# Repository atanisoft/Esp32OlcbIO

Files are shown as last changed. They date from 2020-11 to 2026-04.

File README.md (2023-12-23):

# ESP32 OpenLCB IO Board

The ESP32 OpenLCB IO Board is a basic OpenLCB (LCC) node offering 14 input/output
capable pins, and two that are input only. Additionally all IO pins are exposed
through two 13 pin headers which allows for extending the functionality of 
the base board using a daughter board approach.

## Powering the ESP32 OpenLCB IO Board

The ESP32 OpenLCB IO Board can be powered from an external power supply (12V) on
J5 connector, or using the OpenLCB (LCC) Bus power on RJ45. To enable powering
from the external supply, bridge pins 1 and 2 on JP1. To power from the OpenLCB
(LCC) Bus, bridge pins 2 and 3. Note that when using the USB connector on the
ESP32 module JP1 should not have any pins bridged.

### OpenLCB (LCC) Power requirements

The ESP32 OpenLCB IO Board will draw around 100mA from the OpenLCB (LCC) Bus when
the PWR_POS pin provides 15VDC. If the PWR_POS pin provides less, the node may
draw more current from the bus.

### External Power requirements

The external power supply should be rated for at least 12VDC 500mA to ensure
sufficient current is available for the node to operate as intended.

### Node Brownout detection

If the ESP32 detects a brownout condition it will attempt to produce the
well-known event `01.00.00.00.00.00.FF.F1` soon after startup. This delivery
is not guaranteed.

## Pin Mapping

By default almost all pins are exposed for general IO usage by the node,
however a few pins have specialized usage as part of the screw terminals or
expansion headers.

| GPIO Pin | Usage | Notes |
| --- | ----- | ----- |
| 0 | IO4 | has pull-up resistor |
| 1 | UART0 TX | not exposed |
| 2 | IO5 | has pull-down resistor |
| 3 | UART0 RX | not exposed |
| 4 | CAN RX | has pull-down resistor |
| 5 | CAN TX | has pull-up resistor |
| 6-11 | NOT AVAILABLE | connected to on chip flash |
| 12 | IO7 | has pull-down resistor |
| 13 | IO8 | |
| 14 | IO16 | |
| 15 | IO6 | has pull-up resistor |
| 16 | IO3 | |
| 17 | IO2 | |
| 18 | IO1 | |
| 19 | I2C - SDA | |
| 20 | NOT AVAILABLE | NOT AVAILABLE |
| 21 | I2C - SCL | |
| 22 | Node Activity LED | active low |
| 23 | WiFi Active LED | active low |
| 24 | NOT AVAILABLE | NOT AVAILABLE |
| 25 | IO13 | |
| 26 | IO14 | |
| 27 | IO15 | |
| 28-31 | NOT AVAILABLE | NOT AVAILABLE |
| 32 | IO11 | |
| 33 | IO12 | |
| 34 | IO9 | INPUT ONLY, has pull-up resistor |
| 35 | IO10 | INPUT ONLY |
| 36 (SVP) | User button | INPUT ONLY, has pull-up resistor |
| 37 | NOT AVAILABLE | NOT AVAILABLE |
| 38 | NOT AVAILABLE | NOT AVAILABLE |
| 39 (SVP) | Factory Reset button | INPUT ONLY, has pull-up resistor |

### Input only pins

The four pins marked as INPUT ONLY in the table above have a 10k pull-up to
3v3 and a 100nF capacitor for debounce.

### IO4, IO5, IO6, IO7 Usage Note

IO4 and IO6 typically have a pull-up resistor. IO5 and IO7 typically have a
pull-down resistor that can not be disabled. Keep this in mind as this may
require adjustments to usage patterns.

## Base ESP32 OpenLCB IO PCB

The ESP32 OpenLCB IO Board PCB can be found under the pcb directory and is
provided as both KiCad files and generated Gerber files.

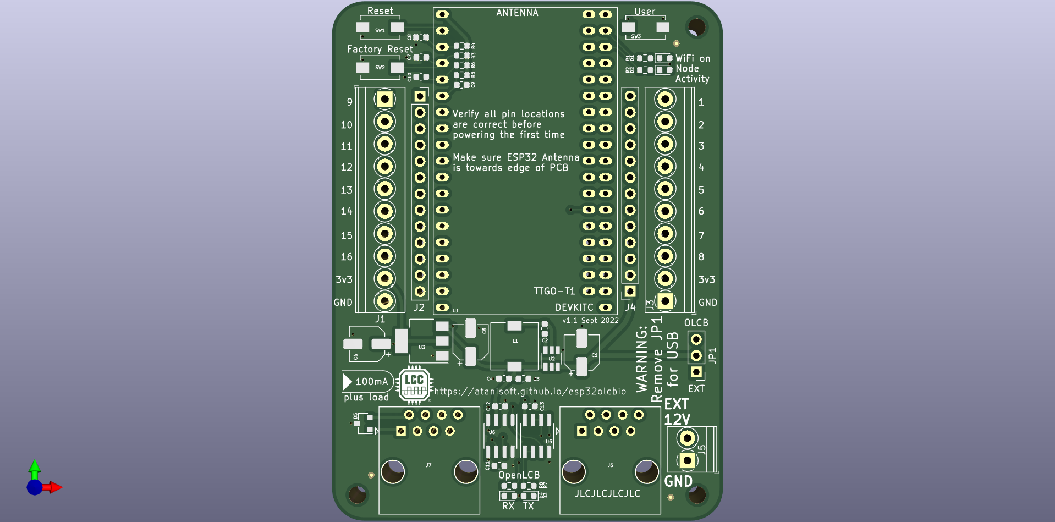
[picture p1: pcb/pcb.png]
PCB Render


**NOTE:** U6 (CAN Transceiver) BOM line item references IFX1050GVIOXUMA1 which is no longer in production, please use one of the following instead:

* TJA1057GT/3J
* TCAN1051
* MCP2562

### PCBWay project

The ESP32 OpenLCB IO PCB has been shared via PCBWay [here](https://www.pcbway.com/project/shareproject/ESP32_OpenLCB__LCC__IO_PCB.html).

### Mouser BOM

The ESP32 OpenLCB IO Board components have been entered on Mouser for easy ordering
via the following shared carts:
- [single PCB](https://www.mouser.com/ProjectManager/ProjectDetail.aspx?AccessID=6d57d6cf6a)
- [five PCBs](https://www.mouser.com/ProjectManager/ProjectDetail.aspx?AccessID=a15be25217)

Ordering in larger quantities can decrease the per-PCB cost considerably. In
the case of resistors and capacitors it is recommended to order 100 of each
as they are tiny and easily lost. Other parts can often be substituted as long
as they have the same footprint and pinout. The pin headers will need to be cut
to length in both of the carts above, in the case of the five PCBs option there
should be enough to populate all five PCBs for the ESP32 *AND* the extension
board (when available).

#### Optional parts

The following parts are optional depending on board usage:

| Part | Mouser # | Notes |
| ---- | --- | ----- |
| J2, J4 | 571-6-534237-1 | These are only needed for attaching an extension daughter board. |
| J5 | 523-NY0210800000G | This is only required if using an external power supply. |

#### Alternative part numbers

The following parts have compatible alternatives:

| Part | Default Mouser # | Alternative Mouser # | Notes |
| ---- | --- | --- | ----- |
| J2, J4 | 571-6-534237-1 | 992-13FX1-254MM, 485-598, 485-4158, 485-4156, 485-4159, 485-4157, 485-4155, 485-4160 | Parts 485-XXXX will need to be cut to the correct length. |
| J6, J7 | 571-5569284-1 | 534-949 or 493-HCJV1-812UK |

## Extending the base board

The ESP32 OpenLCB IO Board can be extended by using the pcb-ext daughter board
files as a basis for creating a compatible extension PCB. This PCB sits on top
of the base board.

### 16 Channel PWM generator expansion

The first expansion board is the 16 Channel PWM generator board, this is usable
for Servo or LED control. This expansion board utilizes a PCA9685 to generate
16 PWM signals which are routed to a three pin header (GND, 5V and PWM) for
each output.

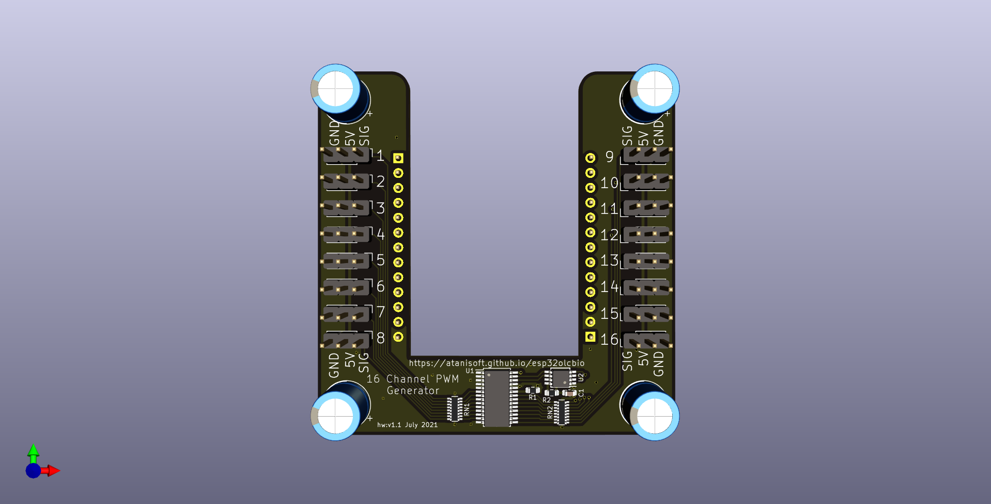
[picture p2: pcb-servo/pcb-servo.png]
Extension PCB as Servo controller


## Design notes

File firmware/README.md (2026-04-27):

# ESP32 OpenLCB IO Board Firmware

## Features

The ESP32 OpenLCB IO Board supports all features of the base IO Board PCB. Some
of the functionality has been customized in this firmware as described below.

### Input/Output pins

The ESP32 OpenLCB IO Board firmware exposes sixteen input/output connections with
two of these being input only. Additionally there are two buttons which can be
used to generate events from the base IO board.

### Factory reset

The Factory Reset button on the base IO Board can be held during startup of the
node to initiate one of the behavors below:

* Hold for five seconds to regenerate event identifiers for all eighteen
input/output pins.
* Hold for ten seconds to erase all OpenLCB (LCC) configuration data and return
the node to it's default configuration. NOTE: This will not clear persistent
WiFi settings.
* Hold both the Factory Reset and User buttons during startup to force the node
into the bootloader download mode. This mode can be used to update the firmware
from within JMRI.
* Press anytime after boot to generate a pair of events.

### User Button

Pressing the User button will generate a pair of events.

## Building

The ESP32 OpenLCB IO Board depends on at least ESP-IDF v5.2.x and will not build with
earlier versions. Note that it will not build successfully avove ESP-IDF v5.4.4 due to
ESP-IDF changes in TWAI and other peripherals.

### Configuring ESP-IDF build environment

For Windows environments please use the [Windows Installer](https://docs.espressif.com/projects/esp-idf/en/latest/esp32/get-started/windows-setup.html)
and select `release/v5.1` when prompted for a version. It is only necessary to
install the basic command line tools, Eclipse (or other IDEs) are optional.

For Linux / Mac environments it is recommended to use `git clone` to setup and
maintain the ESP-IDF build enviornment:
```
git clone https://github.com/espressif/esp-idf.git --depth 1 --branch release/v5.1 esp-idf-v5.1 --recursive
cd esp-idf-v5.1
sh install.sh
```

To use the ESP-IDF build enviornment start a commandline shell and source / run the
`export.sh`, `export.bat` or `export.ps1` script based on your shell.

### Configuring and Building Esp32OlcbIO

Enter the ESP-IDF build environment and navigate to the Esp32OlcbIO source
directory. If this is the first time building the source code it is a good idea
to run `idf.py menuconfig` and configure the default configuration settings for
the Esp32OlcbIO firmware. In general it is not necessary to modify any
configuration settings outside of `OpenLCB Configuration` and `WiFi Configuration`.

Once the configuration has been completed run `idf.py build` to compile the
firmware. If there are no errors you can proceed to programming the firmware.

### Programming the firmware

There are a couple ways to flash the firwmare to the ESP32:

* `idf.py flash` - This leverages the ESP-IDF build environment and should
automatically detect the appropriate communications port for the ESP32.
* [Browser based flash utility](https://espressif.github.io/esptool-js/)

The [Browser based flash utility](https://espressif.github.io/esptool-js/)
only supports using Chrome based browsers, attempting to use Safari will
result in an error dialog being displayed. If you are using this approach,
plug in the ESP32 to an available USB port and click the `Connect` button
which will prompt for the communication port (COM?? on Windows, /dev/ttyACM?
on Linux). Once connected the console output should display information about
the connected ESP32 module.

Enter the following `Flash Address` and `File` using the `Add File` button
as needed:

* 0x1000 - build/bootloader/bootloader.bin
* 0x8000 - build/partition_table/partition-table.bin
* 0xe000 - build/ota_data_initial.bin
* 0x10000 - build/ESP32OlcbIO.bin

Click on `Program` and the binaries will be sent to the ESP32 and it should
reboot automatically.

### Monitoring the firmware startup

After programming a new firmware it is generally a good idea to monitor the
startup of the Esp32OlcbIO firmware to confirm that there are no issues
preventing successful startup.

The easiest way to do this is with `idf.py monitor`.

NOTE: If the ESP32 is *NOT* plugged into the IO PCB it will be necessary to
add a jumper wire between the 3v3 pin and GPIO 39 (may be labeled as SVN or
VN) to prevent Factory Reset from being initiated on startup.

## Updating the firmware

The easiest way to update the firmware on the ESP32 OpenLCB IO Board is to upload
it via the JMRI Firmware Upload tool via the TWAI (CAN) interface since you do not
need to remove the ESP32 OpenLCB IO Board from the train layout. Alternatively,
the updated firmware can be uploaded via the web interface.

If the ESP32 is not connected to the PCB it will be necessary to add a jumper
wire between 3v3 and both the Factory Reset button pin (default 39/SVN) and the
User button pin (default 36/SVP) to prevent the ESP32 from entering bootloader
mode.

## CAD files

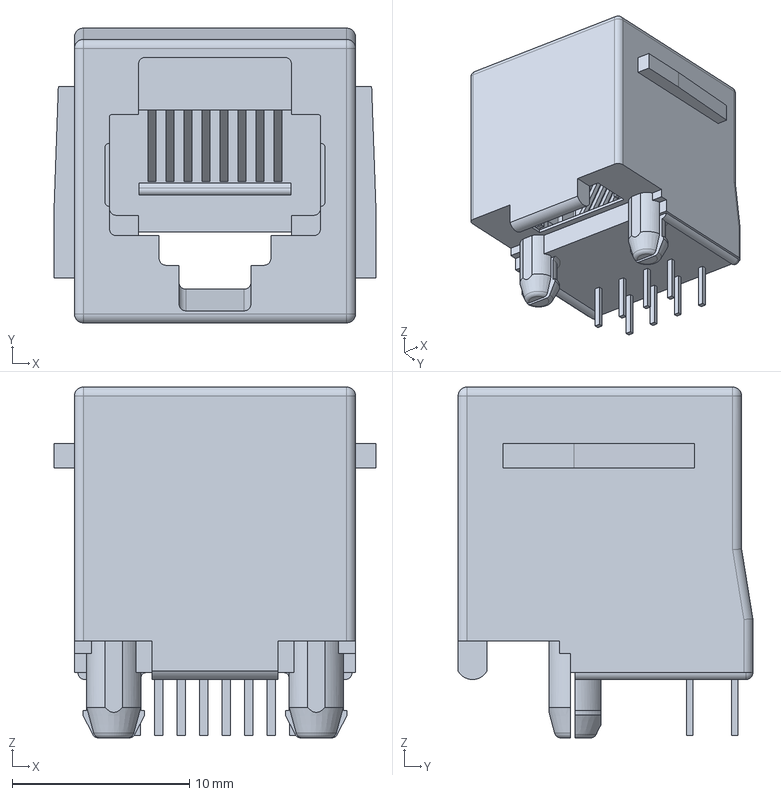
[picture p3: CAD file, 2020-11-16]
pcb/Components/c-5520259-4-c-3d.stp
18.2 x 16.6 x 19.8 mm

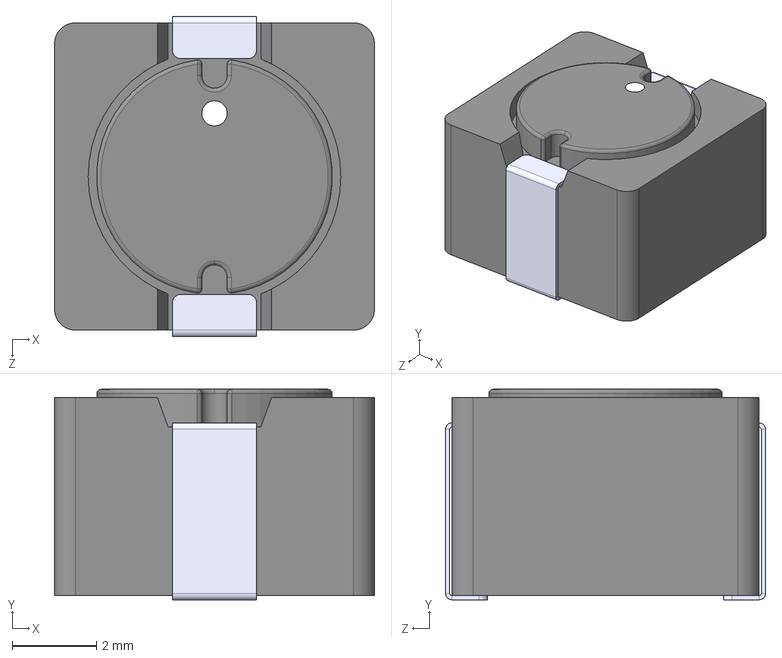
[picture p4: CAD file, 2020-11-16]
pcb/Components/B1047AS-221M=P3--3DModel-STEP-46669.STEP
7.60 x 5.00 x 7.60 mm

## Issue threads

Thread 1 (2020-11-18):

Web: Rework CDIRequestProcessor to queue requests

atanisoft, 2020-11-18:
Currently the code will create N instances of `CDIRequestProcessor` where N is the number of requests. This causes the heap to become dangerously low at times and can lead to heap fragmentation.

It would be better to allocate a single instance of `CDIRequestProcessor` and send it requests similar to `openlcb::MemoryConfigClient`.

Closed 2022-11-25.

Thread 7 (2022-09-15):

Error during compiling esp32io_bootloader.cpp

dwightkelly, 2022-09-15:
a clean clone of the master branch has the compiler error:
```
In file included from ../main/esp32io_bootloader.cpp:39:
../components/OpenMRNIDF/src/freertos_drivers/esp32/Esp32BootloaderHal.hxx: In function 'void esp32_bootloader_run(uint64_t, gpio_num_t, gpio_num_t, bool)':
../components/OpenMRNIDF/src/freertos_drivers/esp32/Esp32BootloaderHal.hxx:354:12: error: enumeration value 'CHIP_ESP32H2' not handled in switch [-Werror=switch]
     switch (chip_info.model)
            ^
```

This enum value was added on 1/7/22 in [0f6073123ebb836d6515858a56661fb36ddd23e5](https://github.com/atanisoft/OpenMRNIDF/commit/0f6073123ebb836d6515858a56661fb36ddd23e5)

The servo branch is using newer version (9/18/22)  [10b7e3cf3c65cf0e71788427e6c3227b100f4802](https://github.com/atanisoft/OpenMRNIDF/commit/10b7e3cf3c65cf0e71788427e6c3227b100f4802)

atanisoft, 2022-09-15:
Master should be pointing to [217a5db2465b9091a106ce9ca476a6f37ec6f4dd](https://github.com/atanisoft/OpenMRNIDF/tree/217a5db2465b9091a106ce9ca476a6f37ec6f4dd) which has no reference to `CHIP_ESP32H2` that I can find.
.
This will be resolved on the `servo` branch which syncs to the latest OpenMRNIDF and switches to ESP-IDF v4.4 (master uses v4.3)

dwightkelly, 2022-09-15:
I must have somehow forced OpenMRNIDF to HEAD.

Closed 2022-11-25.

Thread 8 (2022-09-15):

Add note about firmware update of ESP32 board when removed from IO board

dwightkelly, 2022-09-15:
Add a note about needing to connect SVP (pin 36) and SVN (pin 39) to 3.3v if updating firmware on ESP32 board when it's removed from IO board

Closed 2022-11-25.

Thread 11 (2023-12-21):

Cannot build with esp-idf 4.4

utement, 2023-12-21:
I cant build firmware with esp-idf 4.4. Looks like dependencies don't match.

`
bash-5.2$ idf.py menuconfig
Executing action: menuconfig
Running ninja in directory /Users/utement/Projects/esp/Esp32OlcbIO/firmware/build
Executing "ninja menuconfig"...
[0/1] cd /Users/utement/Projects/esp/Esp32OlcbIO/firmware/build && /Users/utement/.espressif/python_env/idf5....F_TARGET=esp32 --env IDF_ENV_FPGA= --output config /Users/utement/Projects/esp/Esp32OlcbIO/firmware/sdkconfig
Loading defaults file /Users/utement/Projects/esp/Esp32OlcbIO/firmware/sdkconfig.defaults...
/Users/utement/Projects/esp/Esp32OlcbIO/firmware/sdkconfig.defaults:102 CONFIG_ESP_TASK_WDT was replaced with CONFIG_ESP_TASK_WDT_INIT
TERM environment variable is set to "xterm-256color"
/Users/utement/.espressif/python_env/idf5.0_py3.10_env/lib/python3.10/site-packages/menuconfig.py: /Users/utement/Projects/esp/esp-idf-5.0/components/esp_psram/./esp32/Kconfig.spiram:62: '/Users/utement/Projects/esp/esp-idf-4.4/components/esp_psram/Kconfig.spiram.common' not found (in 'source "$IDF_PATH/components/esp_psram/Kconfig.spiram.common"    # insert non-chip-specific items here'). Check that environment variables are set correctly (e.g. $srctree, which is unset or blank). Also note that unset environment variables expand to the empty string.
FAILED: CMakeFiles/menuconfig /Users/utement/Projects/esp/Esp32OlcbIO/firmware/build/CMakeFiles/menuconfig
cd /Users/utement/Projects/esp/Esp32OlcbIO/firmware/build && /Users/utement/.espressif/python_env/idf5.0_py3.10_env/bin/python /Users/utement/Projects/esp/esp-idf-5.0/tools/kconfig_new/prepare_kconfig_files.py --list-separator=semicolon --env-file /Users/utement/Projects/esp/Esp32OlcbIO/firmware/build/config.env && /Users/utement/.espressif/python_env/idf5.0_py3.10_env/bin/python /Users/utement/Projects/esp/esp-idf-5.0/tools/kconfig_new/confgen.py --list-separator=semicolon --kconfig /Users/utement/Projects/esp/esp-idf-5.0/Kconfig --sdkconfig-rename /Users/utement/Projects/esp/esp-idf-5.0/sdkconfig.rename --config /Users/utement/Projects/esp/Esp32OlcbIO/firmware/sdkconfig --defaults /Users/utement/Projects/esp/Esp32OlcbIO/firmware/sdkconfig.defaults --env-file /Users/utement/Projects/esp/Esp32OlcbIO/firmware/build/config.env --env IDF_TARGET=esp32 --env IDF_ENV_FPGA= --dont-write-deprecated --output config /Users/utement/Projects/esp/Esp32OlcbIO/firmware/sdkconfig && /Users/utement/.espressif/python_env/idf5.0_py3.10_env/bin/python /Users/utement/Projects/esp/esp-idf-5.0/tools/check_term.py && /opt/local/bin/cmake -E env COMPONENT_KCONFIGS_SOURCE_FILE=/Users/utement/Projects/esp/Esp32OlcbIO/firmware/build/kconfigs.in COMPONENT_KCONFIGS_PROJBUILD_SOURCE_FILE=/Users/utement/Projects/esp/Esp32OlcbIO/firmware/build/kconfigs_projbuild.in KCONFIG_CONFIG=/Users/utement/Projects/esp/Esp32OlcbIO/firmware/sdkconfig IDF_TARGET=esp32 IDF_ENV_FPGA= /Users/utement/.espressif/python_env/idf5.0_py3.10_env/bin/python -m menuconfig /Users/utement/Projects/esp/esp-idf-5.0/Kconfig && /Users/utement/.espressif/python_env/idf5.0_py3.10_env/bin/python /Users/utement/Projects/esp/esp-idf-5.0/tools/kconfig_new/confgen.py --list-separator=semicolon --kconfig /Users/utement/Projects/esp/esp-idf-5.0/Kconfig --sdkconfig-rename /Users/utement/Projects/esp/esp-idf-5.0/sdkconfig.rename --config /Users/utement/Projects/esp/Esp32OlcbIO/firmware/sdkconfig --defaults /Users/utement/Projects/esp/Esp32OlcbIO/firmware/sdkconfig.defaults --env-file /Users/utement/Projects/esp/Esp32OlcbIO/firmware/build/config.env --env IDF_TARGET=esp32 --env IDF_ENV_FPGA= --output config /Users/utement/Projects/esp/Esp32OlcbIO/firmware/sdkconfig
ninja: build stopped: subcommand failed.
ninja failed with exit code 1
bash-5.2$ idf.py menuconfig
Executing action: menuconfig
Running ninja in directory /Users/utement/Projects/esp/Esp32OlcbIO/firmware/build
Executing "ninja menuconfig"...
[0/1] Re-running CMake...
-- Building ESP-IDF components for target esp32
Solving dependencies requirements
Skipping optional dependency: espressif/mdns
.................................CMake Error at /Users/utement/Projects/esp/esp-idf-4.4/tools/cmake/build.cmake:463 (message):
  HINT: Please check manifest file of the following component(s): main

  ERROR: Because project depends on idf (>=5.0) which doesn't match any
  versions, version solving failed.

Call Stack (most recent call first):
  /Users/utement/Projects/esp/esp-idf-4.4/tools/cmake/project.cmake:476 (idf_build_process)
  CMakeLists.txt:7 (project)

-- Configuring incomplete, errors occurred!
See also "/Users/utement/Projects/esp/Esp32OlcbIO/firmware/build/CMakeFiles/CMakeOutput.log".
FAILED: build.ninja
/opt/local/bin/cmake --regenerate-during-build -S/Users/utement/Projects/esp/Esp32OlcbIO/firmware -B/Users/utement/Projects/esp/Esp32OlcbIO/firmware/build
ninja: error: rebuilding 'build.ninja': subcommand failed
ninja failed with exit code 1
bash-5.2$ idf.py build
Executing action: all (aliases: build)
Running ninja in directory /Users/utement/Projects/esp/Esp32OlcbIO/firmware/build
Executing "ninja all"...
[0/1] Re-running CMake...
-- Building ESP-IDF components for target esp32
Solving dependencies requirements
Skipping optional dependency: espressif/mdns
.................................CMake Error at /Users/utement/Projects/esp/esp-idf-4.4/tools/cmake/build.cmake:463 (message):
  HINT: Please check manifest file of the following component(s): main

  ERROR: Because project depends on idf (>=5.0) which doesn't match any
  versions, version solving failed.

Call Stack (most recent call first):
  /Users/utement/Projects/esp/esp-idf-4.4/tools/cmake/project.cmake:476 (idf_build_process)
  CMakeLists.txt:7 (project)

-- Configuring incomplete, errors occurred!
See also "/Users/utement/Projects/esp/Esp32OlcbIO/firmware/build/CMakeFiles/CMakeOutput.log".
FAILED: build.ninja
/opt/local/bin/cmake --regenerate-during-build -S/Users/utement/Projects/esp/Esp32OlcbIO/firmware -B/Users/utement/Projects/esp/Esp32OlcbIO/firmware/build
ninja: error: rebuilding 'build.ninja': subcommand failed
ninja failed with exit code 1
`

atanisoft, 2023-12-21:
ESP-IDF v4.x is no longer supported, please use ESP-IDF v5.1.2.

utement, 2023-12-23:
I tried with esp-idf 5.2 and 5.1.2, but I wasn't able to build. So after reading documentation I trided 4.4, again I wasnt able to build it. After your suggestion and complete reinstall of 5.1.2 it worked. I'm not sure but looks like I had broken install or something.

Please update documentation. Currently it says: The ESP32 OpenLCB IO Board depends on ESP-IDF v4.4.x and will not build with ESP-IDF v5.0.x at this time.

This issue can be closed now.

atanisoft, 2023-12-23:
Ahh, I missed that it had embedded notes for IDF v4.4 in the firmware tree. I've updated the notes (see commit link below), I haven't tested with IDF v5.2 or master at this time though. Once we have a stable IDF v5.2 I'll be reviewing that for updates.

Closed 2023-12-23.

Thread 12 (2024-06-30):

Build error with ESP-IDF V5.1

whoarreyou, 2024-06-30:
I have tried to run 'idf.py menuconfig' as per the build instructions but I am getting a dependency error as below.

Dependencies lock doesn't exist, solving dependencies.
..............CMake Error at C:/Espressif/frameworks/esp-idf-v5.1/tools/cmake/build.cmake:540 (message):
  ERROR: Because OpenMRNIDF (ec40a9bca38b87ca3a19a2b68bcf5fe8637fb487)
  depends on espressif/mdns (*) which doesn't match any versions, OpenMRNIDF
  is forbidden.

  So, because project depends on OpenMRNIDF
  (ec40a9bca38b87ca3a19a2b68bcf5fe8637fb487), version solving failed.

Call Stack (most recent call first):
  C:/Espressif/frameworks/esp-idf-v5.1/tools/cmake/project.cmake:604 (idf_build_process)
  CMakeLists.txt:7 (project)

-- Configuring incomplete, errors occurred!
See also "C:/Users/User/Documents/IOBoard/Esp32OlcbIO-master/Esp32OlcbIO-master/firmware/build/CMakeFiles/CMakeOutput.log".
cmake failed with exit code 1

atanisoft, 2024-07-01:
This looks like a bug in the ESP-IDF v5.1 dependency resolver and not specific to this repository / OpenMRNIDF. When I last tested this (~7mo ago) with ESP-IDF v5.1.x it was working correctly.

Are you using PlatformIO's version of ESP-IDF?

atanisoft, 2024-07-01:
Also of note:
```
Processing 6 dependencies:
[1/6] HttpServer (c637c66f6261d8dc52ef0b55e7deb1b88d10306d)
[2/6] OpenMRNIDF (ec40a9bca38b87ca3a19a2b68bcf5fe8637fb487)
[3/6] espressif/esp_tinyusb (1.4.4)
[4/6] espressif/mdns (1.3.2)
[5/6] espressif/tinyusb (0.15.0~10)
[6/6] idf (5.2.2)
```
This is using ESP-IDF v5.2.2 (checked out tagged release of Espressif's repository) with OpenMRNIDF 5.1.0 branch listed as dependency

atanisoft, 2024-07-01:
Can you check which version of the idf_component_manager you currently are using? You can check this by running `$IDF_PYTHON_ENV_PATH/lib/python*/site-packages/idf_component_manager*` and checking the `Version` line. If it is less than version 1.5.2 you likely will need to update it as that version fixed a few bugs in the version resolver.

This updated version is also included in ESP-IDF v1.5.3 or v1.5.4.

whoarreyou, 2024-07-01:
Hi Mike, thanks for your help with this. Component manager version was 1.5.3. I was using the Espressif online installer, I tried several versions yesterday, all with the same results. I have now used the v5.2.2 offline installer and it has compiled and is working as expected. So I think you were correct, a bug or installation issue.
Thanks again for your help.

atanisoft, 2024-07-01:
Very interesting, I'll see if I can reproduce with the latest ESP-IDF v5.1.x tagged release. If it does reproduce I'll see if I can figure out what broke it.

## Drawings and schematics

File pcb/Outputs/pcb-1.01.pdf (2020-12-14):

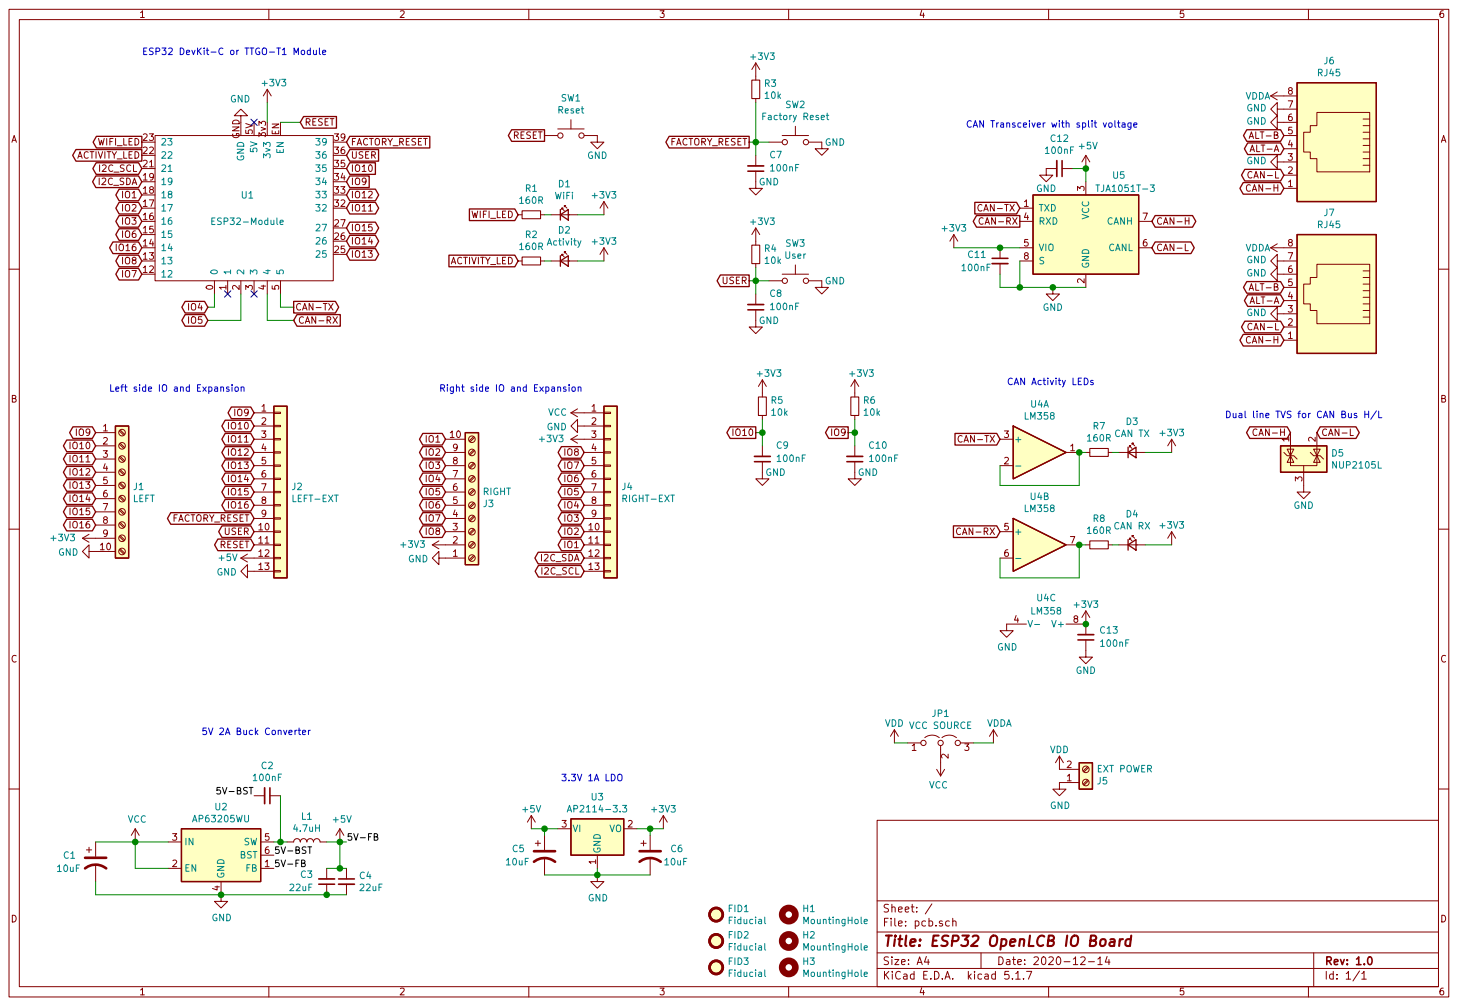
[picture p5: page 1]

Dual line TVS for CAN Bus H/L ESP32 DevKit-C or TTGO-T1 Module

5 5V 5V EN EN GND GND U1 ESP32-Module +3V3C8

CAN Transceiver with split voltage

3 RXD 4 VIO 5 CANL 6 CANH 7 S

Right side IO and Expansion

File: pcb.sch Sheet: /
Id: 1/1 Title: ESP32 OpenLCB IO Board

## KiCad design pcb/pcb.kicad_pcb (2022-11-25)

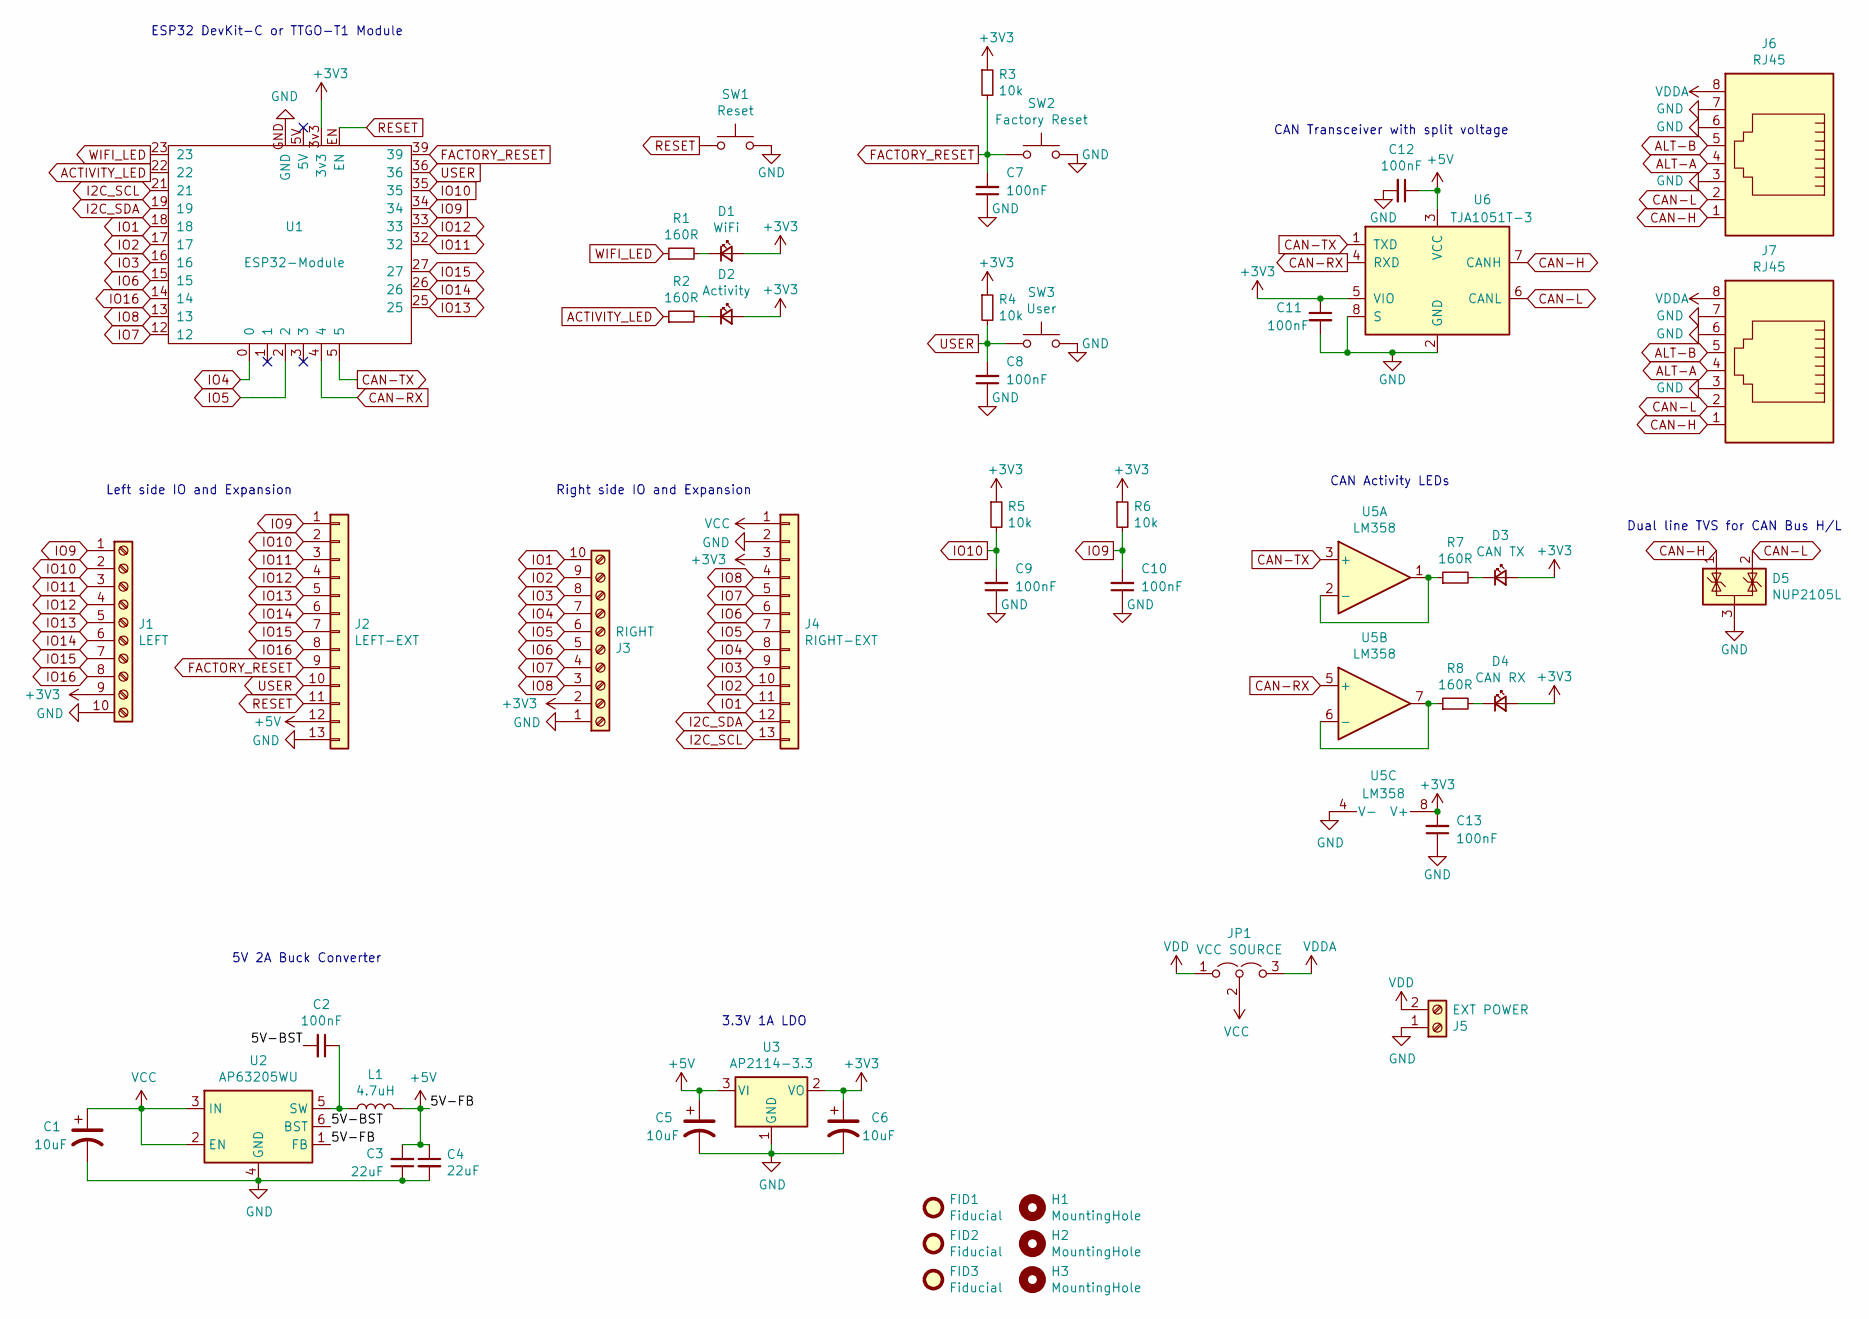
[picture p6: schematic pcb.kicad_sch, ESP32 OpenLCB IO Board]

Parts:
C1, C5, C6: 10uF; CP_Elec_5x5.3; Mouser 710-865230542002
C2, C7, C8, C9, C10, C11, C12, C13: 100nF; C_0603_1608Metric; Mouser 710-885012206020
C3, C4: 22uF; C_0603_1608Metric; Mouser 603-CC0603MRX6S5B226
D1: WiFi; LED_0603_1608Metric; Mouser 710-150060VS55040
D2: Activity; LED_0603_1608Metric; Mouser 710-150060AS75000
D3: CAN TX; LED_0603_1608Metric; Mouser 710-150060YS75000
D4: CAN RX; LED_0603_1608Metric; Mouser 710-150060AS75000
D5: NUP2105L; SOT-23; Mouser 863-SZNUP2105LT3G
FID1, FID2, FID3: Fiducial; Fiducial_0.5mm_Mask1mm
H1, H2, H3: MountingHole; MountingHole_2.7mm_M2.5
J1: LEFT; TerminalBlock_Phoenix_PT-1,5-10-3.5-H_1x10_P3.50mm_Horizont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; Mouser 649-220327-C101B01LF
J2: LEFT-EXT; PinSocket_1x13_P2.54mm_Vertical; Mouser 571-6-534237-1 or 992-13FX1-254MM
J3: RIGHT; TerminalBlock_Phoenix_PT-1,5-10-3.5-H_1x10_P3.50mm_Horizont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; Mouser 649-220327-C101B01LF
J4: RIGHT-EXT; PinSocket_1x13_P2.54mm_Vertical; Mouser 571-6-534237-1 or 992-13FX1-254MM
J5: EXT POWER; TerminalBlock_Phoenix_PT-1,5-2-3.5-H_1x02_P3.50mm_Horizontal; Mouser 651-1984617
J6, J7: RJ45; RJ45_OST_PJ012-8P8CX_Vertical; Mouser 571-5569284-1 or 534-949 or 493-HCJV1-8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
JP1: VCC SOURCE; PinHeader_1x03_P2.54mm_Vertical; Mouser 538-22-28-9034
L1: 4.7uH; L_7.3x7.3_H4.5; Mouser 81-B1047AS-4R7NP3
R1, R2, R7, R8: 160R; R_0603_1608Metric; Mouser 603-AC0603JR-07160RL
R3, R4, R5, R6: 10k; R_0603_1608Metric; Mouser 71-CRCW06030000Z0EAC
SW1: Reset; SW_SPST_EVQPE1; Mouser 667-EVQ-PE104K
SW2: Factory Reset; SW_SPST_EVQPE1; Mouser 667-EVQ-PE104K
SW3: User; SW_SPST_EVQPE1; Mouser 667-EVQ-PE104K
U1: ESP32-Module; TTGO-T1-DEVKIT-C
U2: AP63205WU; TSOT-23-6; Mouser 621-AP63205WU-7
U3: AP2114-3.3; SOT-223-3_TabPin2; Mouser 621-AP2114H-3.3TRG1
U5: LM358; SOIC-8_3.9x4.9mm_P1.27mm; Mouser 595-LM358BIDR
U6: TJA1051T-3; SOIC-8_3.9x4.9mm_P1.27mm; Mouser 726-IFX1050GVIOXUMA1

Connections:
+3V3: C6.1, C11.1, C13.2, D1.2 (A), D2.2 (A), D3.2 (A), D4.2 (A), J1.9, J3.2, J4.3, R3.1, R4.1, R5.1, R6.1, U1.3v3, U3.2 (VO), U5.8 (V+), U6.5 (VIO)
+5V: C3.2, C4.1, C5.1, C12.1, J2.12, L1.2, U2.1 (FB), U3.3 (VI), U6.3 (VCC)
/5V-BST: C2.2, U2.6 (BST)
ACTIVITY_LED: R2.1, U1.22
ALT-A: J6.4, J7.4
ALT-B: J6.5, J7.5
CAN-H: D5.1 (K), J6.1, J7.1, U6.7 (CANH)
CAN-L: D5.2 (K), J6.2, J7.2, U6.6 (CANL)
CAN-RX: U1.4, U5.5 (+), U6.4 (RXD)
CAN-TX: U1.5, U5.3 (+), U6.1 (TXD)
FACTORY_RESET: C7.2, J2.9, R3.2, SW2.1, U1.39
GND: C1.2, C3.1, C4.2, C5.2, C6.2, C7.1, C8.1, C9.1, C10.1, C11.2, C12.2, C13.1, D5.3 (A), J1.10, J2.13, J3.1, J4.2, J5.1, J6.3, J6.6, J6.7, J7.3, J7.6, J7.7, SW1.2, SW2.2, SW3.2, U1.GND, U2.4 (GND), U3.1 (GND), U5.4 (V-), U6.2 (GND), U6.8 (S)
I2C_SCL: J4.13, U1.21
I2C_SDA: J4.12, U1.19
IO1: J3.10, J4.11, U1.18
IO2: J3.9, J4.10, U1.17
IO3: J3.8, J4.9, U1.16
IO4: J3.7, J4.8, U1.0
IO5: J3.6, J4.7, U1.2
IO6: J3.5, J4.6, U1.15
IO7: J3.4, J4.5, U1.12
IO8: J3.3, J4.4, U1.13
IO9: C10.2, J1.1, J2.1, R6.2, U1.34
IO10: C9.2, J1.2, J2.2, R5.2, U1.35
IO11: J1.3, J2.3, U1.32
IO12: J1.4, J2.4, U1.33
IO13: J1.5, J2.5, U1.25
IO14: J1.6, J2.6, U1.26
IO15: J1.7, J2.7, U1.27
IO16: J1.8, J2.8, U1.14
unnamed: C2.1, L1.1, U2.5 (SW)
unnamed: D1.1 (K), R1.2
unnamed: D2.1 (K), R2.2
unnamed: D3.1 (K), R7.2
unnamed: D4.1 (K), R8.2
unnamed: R7.1, U5.1, U5.2 (-)
unnamed: R8.1, U5.6 (-), U5.7
RESET: J2.11, SW1.1, U1.EN
USER: C8.2, J2.10, R4.2, SW3.1, U1.36
VCC: C1.1, J4.1, JP1.2 (C), U2.2 (EN), U2.3 (IN)
VDD: J5.2, JP1.1 (A)
VDDA: J6.8, J7.8, JP1.3 (B)
WIFI_LED: R1.1, U1.23

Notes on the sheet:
Right side IO and Expansion
5V 2A Buck Converter
Left side IO and Expansion
3.3V 1A LDO
ESP32 DevKit-C or TTGO-T1 Module
CAN Transceiver with split voltage
CAN Activity LEDs
Dual line TVS for CAN Bus H/L

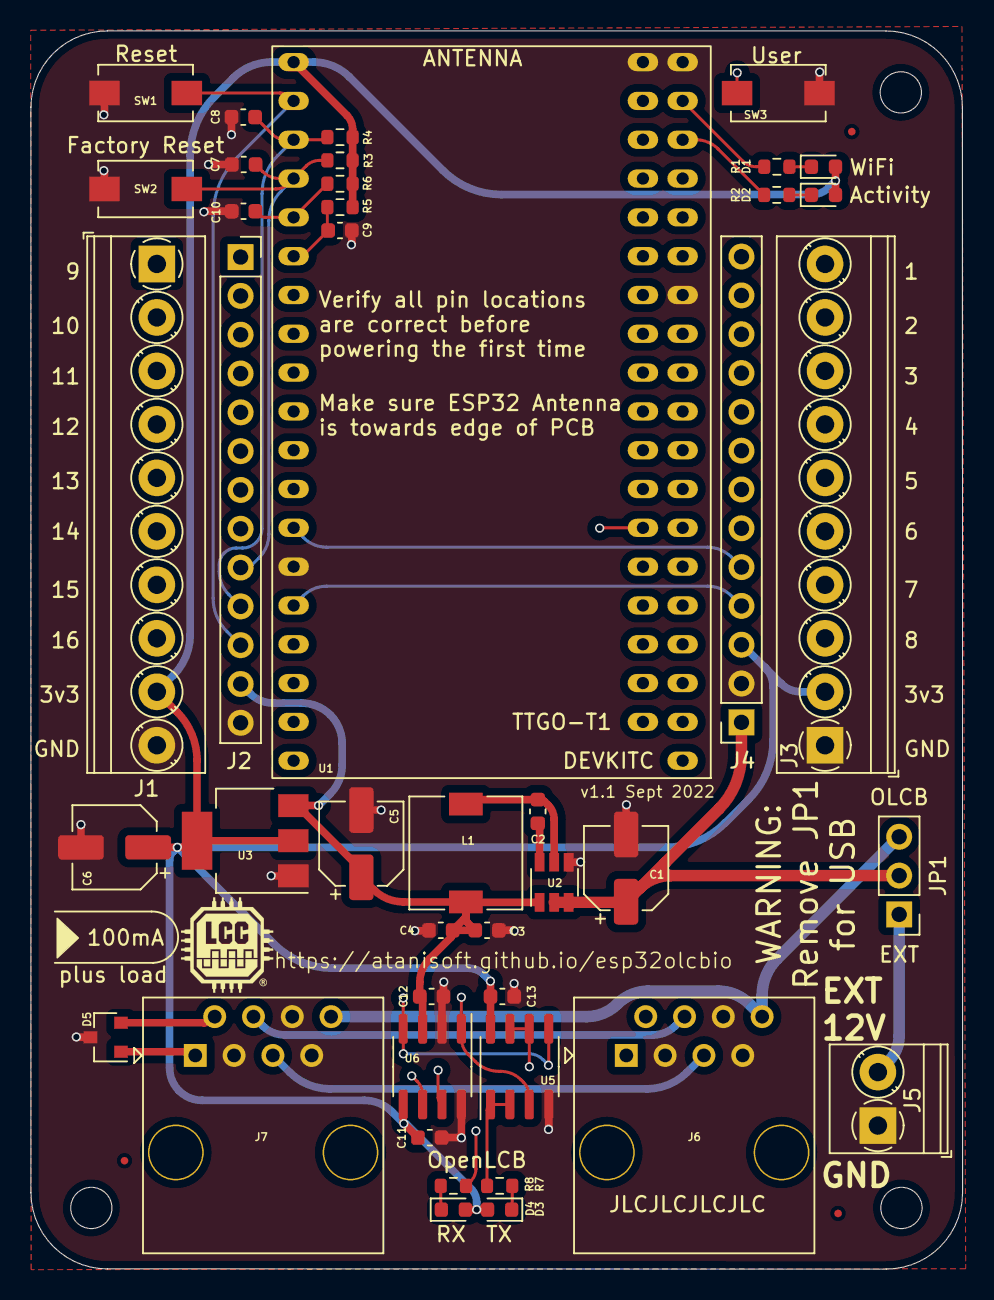
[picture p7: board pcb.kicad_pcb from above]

Board: 4 copper layers, 61.0 x 81.0 mm, 49 parts (0 on the bottom side), 43 nets.

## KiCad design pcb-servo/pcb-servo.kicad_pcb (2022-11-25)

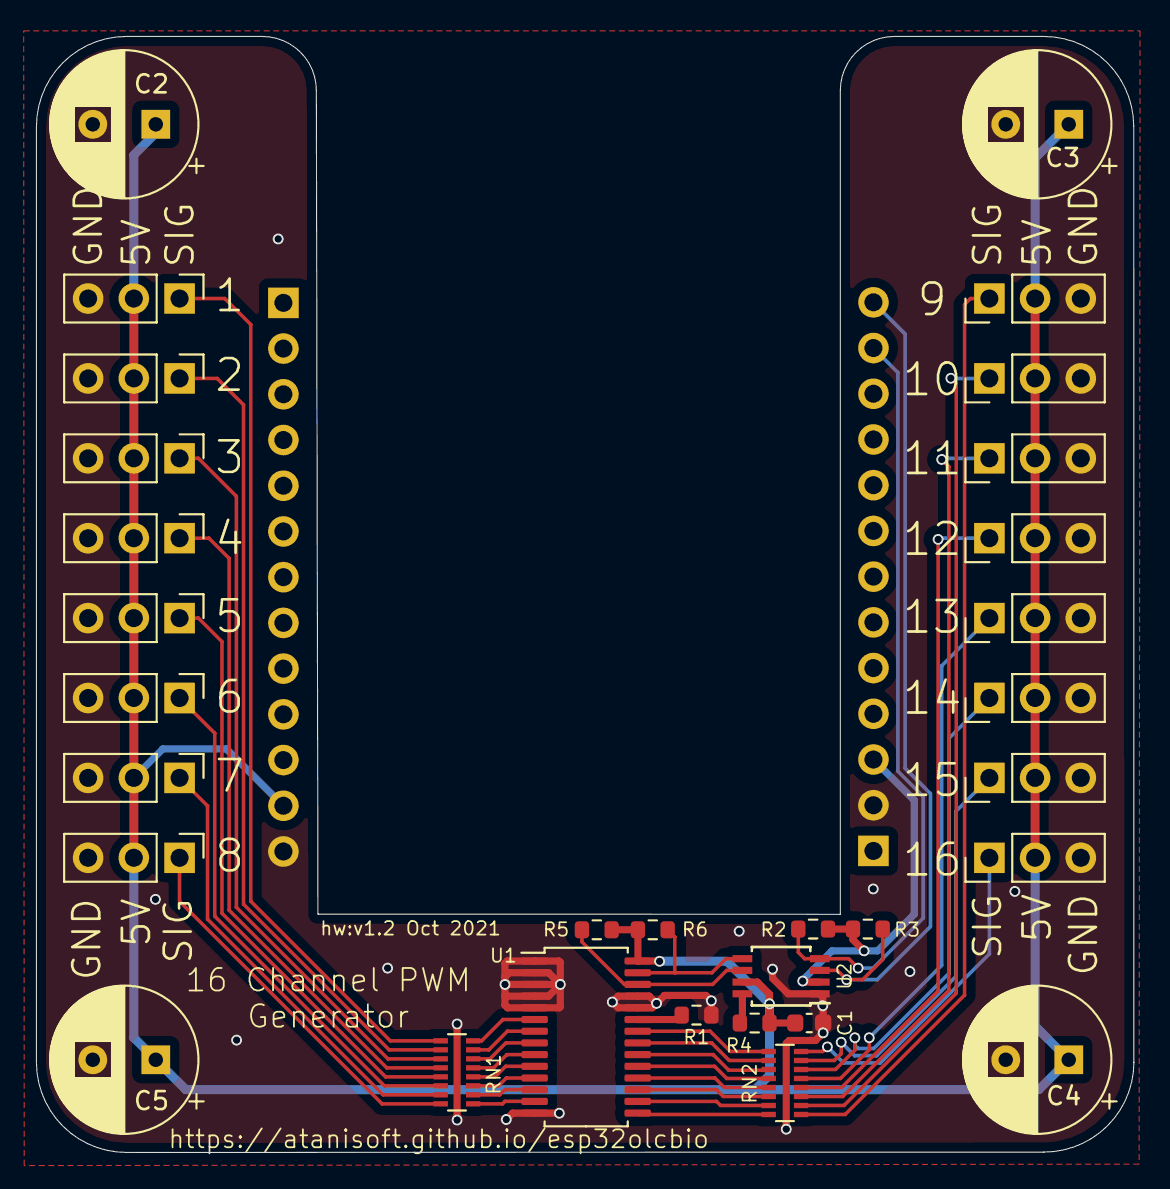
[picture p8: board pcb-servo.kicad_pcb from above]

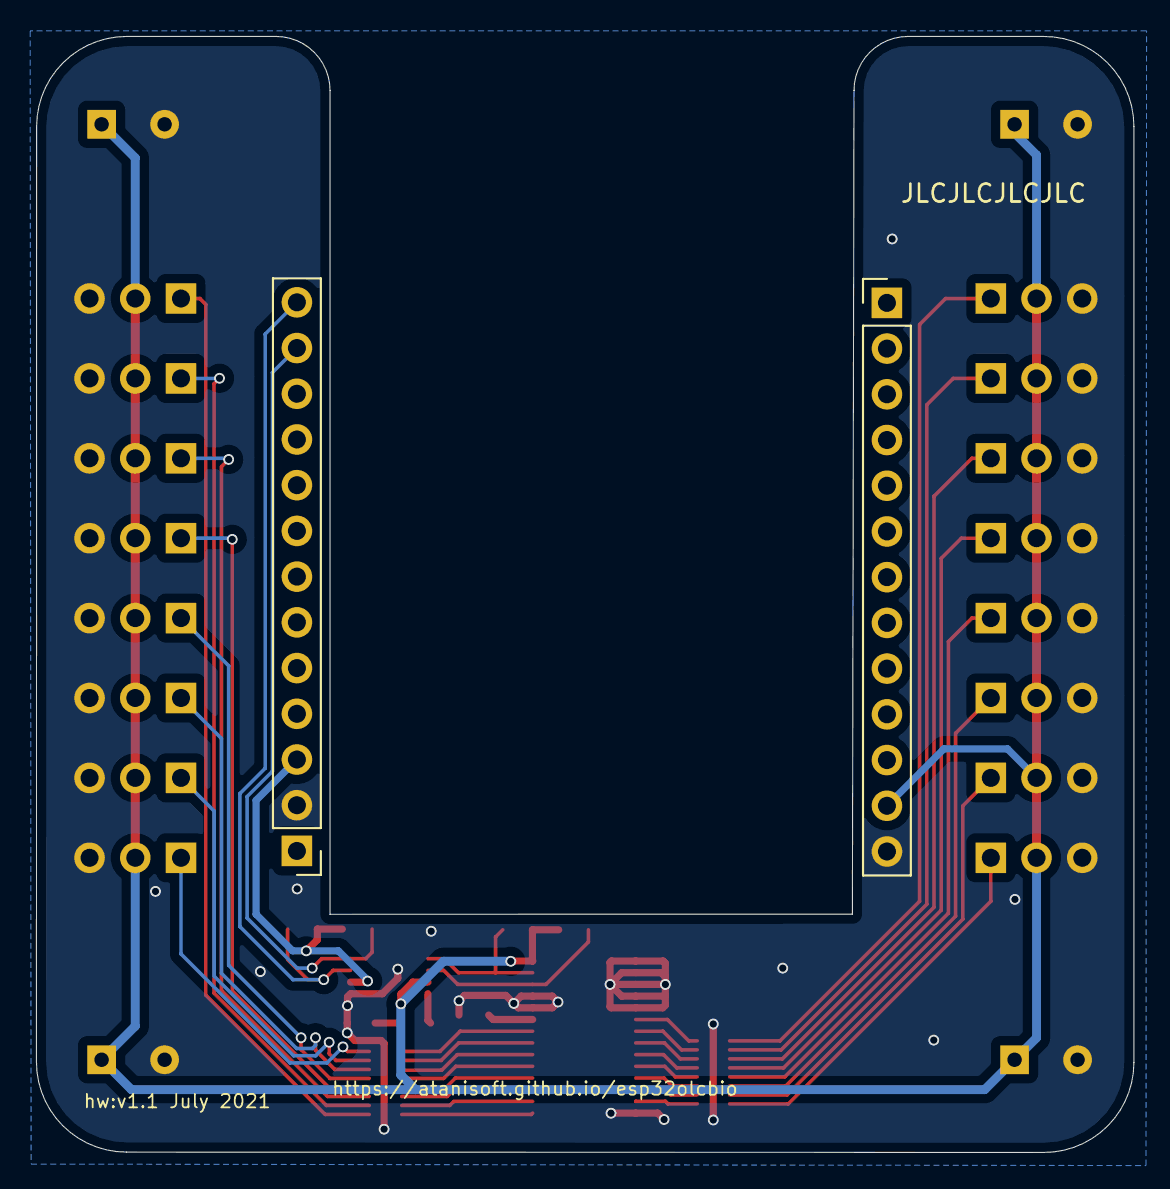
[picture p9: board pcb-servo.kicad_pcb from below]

Board: 2 copper layers, 61.0 x 62.0 mm, 33 parts (2 on the bottom side), 41 nets.

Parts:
C1: 10uF; C_0603_1608Metric
C2, C3, C4, C5: DNP; CP_Radial_D8.0mm_P3.50mm
J1, J2, J3, J4, J5, J6, J7, J8, J9, J10, J11, J12, J13, J14, J15, J16: PWM; PinHeader_1x03_P2.54mm_Vertical
J17: LEFT-EXT; PinHeader_1x13_P2.54mm_Vertical
J18: RIGHT-EXT; PinHeader_1x13_P2.54mm_Vertical
R1: 10K; R_0603_1608Metric
R2, R3: 2K4; R_0603_1608Metric
R4: 200K; R_0603_1608Metric
R5, R6: 4k7; R_0603_1608Metric
RN1, RN2: 220R; R_Array_Convex_8x0602
U1: PCA9685PW; TSSOP-28_4.4x9.7mm_P0.65mm
U2: PCA9306; TSSOP-8_3x3mm_P0.65mm

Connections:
5V_I2C_SCL: R5.2, U1.26, U2.6
5V_I2C_SDA: R6.2, U1.27, U2.5
+3V3: J18.3, R2.1, R3.1, U2.2
+5V: C1.1, C2.1, C3.1, C4.1, C5.1, J1.2, J2.2, J3.2, J4.2, J5.2, J6.2, J7.2, J8.2, J9.2, J10.2, J11.2, J12.2, J13.2, J14.2, J15.2, J16.2, J17.12, R4.1, R5.1, R6.1, U1.28, U2.7
GND: C1.2, C2.2, C3.2, C4.2, C5.2, J1.3, J2.3, J3.3, J4.3, J5.3, J6.3, J7.3, J8.3, J9.3, J10.3, J11.3, J12.3, J13.3, J14.3, J15.3, J16.3, J17.13, J18.2, R1.2, U1.1, U1.2, U1.3, U1.4, U1.5, U1.14, U1.24, U1.25, U2.1
I2C_SCL: J18.13, R3.2, U2.3
I2C_SDA: J18.12, R2.2, U2.4
unnamed: R1.1, U1.23
unnamed: R4.2, U2.8
unnamed: RN1.9, U1.13
unnamed: RN1.10, U1.12
unnamed: RN1.11, U1.11
unnamed: RN1.12, U1.10
unnamed: RN1.13, U1.9
unnamed: RN1.14, U1.8
unnamed: RN1.15, U1.7
unnamed: RN1.16, U1.6
unnamed: RN2.1, U1.22
unnamed: RN2.2, U1.21
unnamed: RN2.3, U1.20
unnamed: RN2.4, U1.19
unnamed: RN2.5, U1.18
unnamed: RN2.6, U1.17
unnamed: RN2.7, U1.16
unnamed: RN2.8, U1.15
PWM-1: J1.1, RN1.1
PWM-2: J5.1, RN1.2
PWM-3: J9.1, RN1.3
PWM-4: J13.1, RN1.4
PWM-5: J2.1, RN1.5
PWM-6: J6.1, RN1.6
PWM-7: J10.1, RN1.7
PWM-8: J14.1, RN1.8
PWM-9: J3.1, RN2.9
PWM-10: J7.1, RN2.10
PWM-11: J11.1, RN2.11
PWM-12: J15.1, RN2.12
PWM-13: J4.1, RN2.13
PWM-14: J8.1, RN2.14
PWM-15: J12.1, RN2.15
PWM-16: J16.1, RN2.16

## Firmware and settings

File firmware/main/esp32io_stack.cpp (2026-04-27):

/** \copyright
 * Copyright (c) 2020, Mike Dunston
 * All rights reserved.
 *
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
 * \file esp32io_stack.cpp
 *
 * OpenMRN Stack stack initialization.
 *
 * @author Mike Dunston
 * @date 1 September 2020
 */

#include "sdkconfig.h"
#include "cdi.hxx"
#include "DelayRebootHelper.hxx"
#include "EventBroadcastHelper.hxx"
#include "FactoryResetHelper.hxx"
#include "fs.hxx"
#include "hardware.hxx"
#include "HealthMonitor.hxx"
#include "NodeRebootHelper.hxx"
#include "nvs_config.hxx"
#include "PCA9685PWM.hxx"
#include "web_server.hxx"

#include <CDIXMLGenerator.hxx>
#include <freertos_drivers/esp32/Esp32HardwareTwai.hxx>
#include <freertos_drivers/esp32/Esp32WiFiManager.hxx>
#include <openlcb/MemoryConfigClient.hxx>
#include <openlcb/RefreshLoop.hxx>
#include <openlcb/ServoConsumer.hxx>
#include <openlcb/SimpleStack.hxx>
#include <utils/constants.hxx>
#include <utils/format_utils.hxx>
#include <utils/Uninitialized.hxx>

namespace esp32io
{

ConfigDef cfg(0);

}

namespace openlcb
{
    // Path to where OpenMRN should persist general configuration data.
    const char *const CONFIG_FILENAME = "/fs/config";

    // The size of the memory space to export over the above device.
    const size_t CONFIG_FILE_SIZE =
        esp32io::cfg.seg().size() + esp32io::cfg.seg().offset();

    // Default to store the dynamic SNIP data is stored in the same persistant
    // data file as general configuration data.
    const char *const SNIP_DYNAMIC_FILENAME = "/fs/config";

    /// Defines the identification information for the node. The arguments are:
    ///
    /// - 4 (version info, always 4 by the standard
    /// - Manufacturer name
    /// - Model name
    /// - Hardware version
    /// - Software version
    ///
    /// This data will be used for all purposes of the identification:
    ///
    /// - the generated cdi.xml will include this data
    /// - the Simple Node Ident Info Protocol will return this data
    /// - the ACDI memory space will contain this data.
    const SimpleNodeStaticValues SNIP_STATIC_DATA =
    {
        4,
        SNIP_PROJECT_PAGE,
        SNIP_PROJECT_NAME,
        SNIP_HW_VERSION " " CONFIG_IDF_TARGET,
        SNIP_SW_VERSION
    };

} // namespace openlcb

extern "C" void enter_bootloader()
{
    node_config_t config;
    if (load_config(&config) != ESP_OK)
    {
        default_config(&config);
    }
    config.bootloader_req = true;
    save_config(&config);
    LOG(INFO, "[Bootloader] Rebooting into bootloader");
    reboot();
}

/// Halts execution with a specific blink pattern for the two LEDs that are on
/// the IO base board.
///
/// @param wifi Sets the initial state of the WiFi LED.
/// @param activity Sets the initial state of the Activity LED.
/// @param period Sets the delay between blinking the LED(s).
/// @param toggle_both Controls if both LEDs will blink or if only the activity
/// LED will blink.
void die_with(bool wifi, bool activity, unsigned period = 1000
            , bool toggle_both = false)
{
    LED_WIFI_Pin::set(wifi);
    LED_ACTIVITY_Pin::set(activity);

    while(true)
    {
        if (toggle_both)
        {
            LED_WIFI_Pin::toggle();
        }
        LED_ACTIVITY_Pin::toggle();
        usleep(period);
    }
}

namespace esp32io
{
int config_fd;
uninitialized<openlcb::SimpleCanStack> stack;
uninitialized<Esp32WiFiManager> wifi_manager;
uninitialized<openlcb::MemoryConfigClient> memory_client;
uninitialized<FactoryResetHelper> factory_reset_helper;
uninitialized<EventBroadcastHelper> event_helper;
uninitialized<DelayRebootHelper> delayed_reboot;
uninitialized<HealthMonitor> health_mon;
uninitialized<NodeRebootHelper> node_reboot_helper;
uninitialized<openlcb::ConfiguredProducer> inputs[ARRAYSIZE(INPUT_ONLY_GPIO)];
uninitialized<openlcb::MultiConfiguredPC> multi_pc;
std::unique_ptr<openlcb::RefreshLoop> refresh_loop;
#if CONFIG_OLCB_ENABLE_TWAI
Esp32HardwareTwai twai(CONFIG_TWAI_RX_PIN, CONFIG_TWAI_TX_PIN);
#endif // CONFIG_OLCB_ENABLE_TWAI

#if CONFIG_OLCB_ENABLE_PWM
PCA9685PWM pca9685(CONFIG_SDA_PIN, CONFIG_SCL_PIN, PCA9685_ADDR, 1000);
uninitialized<PCA9685PWMBit> pca9685PWM[16];
uninitialized<openlcb::ServoConsumer> servos[16];
#endif // CONFIG_OLCB_ENABLE_PWM

void factory_reset_events()
{
    LOG(WARNING, "[CDI] Resetting event IDs");
    stack->factory_reset_all_events(cfg.seg().internal_config()
                                  , stack->node()->node_id(), config_fd);
    fsync(config_fd);
}

void NodeRebootHelper::reboot()
{
    // make sure we are not called from the executor thread otherwise there
    // will be a deadlock
    HASSERT(os_thread_self() != stack->executor()->thread_handle());
    shutdown_webserver();
    LOG(INFO, "[Reboot] Shutting down LCC executor...");
    stack->executor()->sync_run([&]()
    {
        close(config_fd);
        unmount_fs();
        // restart the node
        LOG(INFO, "[Reboot] Restarting!");
        esp_restart();
    });
}

void EventBroadcastHelper::send_event(uint64_t eventID)
{
    stack->executor()->add(new CallbackExecutable([&]()
    {
        stack->send_event(eventID);
    }));
}

template<const unsigned num, const char separator>
void inject_seperator(std::string & input)
{
    for (auto it = input.begin(); (num + 1) <= std::distance(it, input.end());
        ++it)
    {
        std::advance(it, num);
        it = input.insert(it, separator);
    }
}

ConfigUpdateListener::UpdateAction FactoryResetHelper::apply_configuration(
    int fd, bool initial_load, BarrierNotifiable *done)
{
    // nothing to do here as we do not load config
    AutoNotify n(done);
    LOG(VERBOSE, "[CFG] apply_configuration(%d, %d)", fd, initial_load);

    return ConfigUpdateListener::UpdateAction::UPDATED;
}

void FactoryResetHelper::factory_reset(int fd)
{
    LOG(INFO, "[CFG] factory_reset(%d)", fd);
    // set the name of the node to the SNIP model name
    cfg.userinfo().name().write(fd, openlcb::SNIP_STATIC_DATA.model_name);
    string node_id = uint64_to_string_hex(stack->node()->node_id(), 12);
    std::replace(node_id.begin(), node_id.end(), ' ', '0');
    inject_seperator<2, '.'>(node_id);
    // set the node description to the node id in expanded hex format.
    cfg.userinfo().description().write(fd, node_id.c_str());

    // set the default names of the input only pins.
    auto inputs = cfg.seg().gpi();
    for (size_t idx = 0; idx < ARRAYSIZE(INPUT_ONLY_GPIO_NAMES); idx++)
    {
        inputs.entry(idx).description().write(fd, INPUT_ONLY_GPIO_NAMES[idx]);
    }
    // set the default names of the configurable pins.
    auto config_io = cfg.seg().gpio();
    for (size_t idx = 0; idx < ARRAYSIZE(CONFIGURABLE_GPIO_NAMES); idx++)
    {
        config_io.entry(idx).pc().description().write(fd, CONFIGURABLE_GPIO_NAMES[idx]);
    }
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

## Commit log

2020-11-16 :sparkles: Initial Commit
    [B1047AS-221M=P3--3DModel-STEP-46669.STEP, c-5520259-4-c-3d.stp, esp32io-partitions.csv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]
2020-11-17 :sparkles: Daughter board template
    [pcb-ext.kicad_pcb, pcb-ext.sch]
2020-11-17 :pencil: Initial pass at firmware and updates to the PCB.
    [pcb.kicad_pcb, pcb.sch]
2020-11-17 :pencil: Add Mouser part numbers to BOM
    [pcb.kicad_pcb, pcb.sch]
2020-11-18 :pencil: Corrections to part numbers
    * C2 should have been 100nF and not 22uF
    * U3 needs to be able to provide 1A and not 600mA.
    [pcb.kicad_pcb, pcb.sch]
2020-11-18 :sparkles: Add "Reset Event IDs" to web interface :sparkles: Add "Refresh All" to web interface :pencil: Reformat event IDs so they show up as 00.00.00.00.00.00.00.00 instead of 0000000000000000. :pe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
    [esp32io_stack.cpp]
2020-11-19 :pencil: Update readme with alternative part numbers and extension board examples.
2020-11-19 :pencil: Update schematic with a few part alternatives
    [pcb.sch]
2020-11-19 :pencil: Add Fiducials to PCB :pencil: Adjust LED colors so they are not all red
    [pcb.kicad_pcb, pcb.sch]
2020-11-20 :sparkles: Add ability to set the SoftAP Channel via config. :pencil: Add validation of submodules presence. :pencil: Add die_with function to set blink pattern for NVS failure. :pencil: Add factory 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
    [esp32io_stack.cpp]
2020-11-28 :pencil: correct factory/user event handler
    [esp32io_stack.cpp]
2020-11-28 :sparkles: Add "test" button for events
2020-11-29 :pencil: Re-enable ability to reset node-id from web
    [esp32io_stack.cpp]
2020-12-02 :pencil: Correct BOM reference for 3v3 LDO
    [pcb.kicad_pcb, pcb.sch]
2020-12-05 :pencil: PCB BOM update
    [pcb.kicad_pcb, pcb.sch]
2020-12-05 :pencil: Switch to async TWAI
2020-12-07 :pencil: Adjust Mouser BOM links.
2020-12-14 pcb update for rename of repo
    [pcb.kicad_pcb, pcb.sch]
2020-12-27 :pencil: Add notes of ADC channels for IO pins.
2020-12-27 :pencil: Switch to build instead of app.
2020-12-28 :ambulance: Fix SoftAP mode.
    For WPA (all variants) the minimum password length is eight characters, the default password being used previously was seven characters. With this change the SoftAP name and password will now be "esp32olcbio".
    Added new behavior on the User button during startup. When only the User button is held during startup the WiFi debug diagnostics will be enabled and printed to the serial console.
    [esp32io_stack.cpp]
2020-12-28 :arrow_up: Sync OpenMRNLite to pick up WiFi fix.
    [esp32io_stack.cpp]
2020-12-28 :pencil: Switch to Docker based build
2021-05-10 :sparkles: Adding very basic Arduino based firmware.
    This does not include the full functionality available with the ESP-IDF firmware but does provide a starting point for those that prefer an Arduino compatible firmware.
    [partitions.csv]
2021-10-16 :tractor: Dependency refresh (#6)
    * :tractor: Dependency refresh
    * :tractor: Move web interface to use spectre.css
    * :arrow_up: Bump to latest OpenMRNIDF
    [partitions.csv]
2022-11-25 PCA9685 support (#9)
    * Sync PWM changes
    * bump build to IDF v4.4
    * Bump dependencies
    * refresh web interface for new servo config
    * Fix https://github.com/atanisoft/Esp32OlcbIO/issues/8
    * PCB updates for KiCad6
    * IO PCB v1.1
    Spaced out RJ45 jacks to provide easier access to USB connector.
    Fixes: https://github.com/atanisoft/Esp32OlcbIO/issues/3
    * drop old project files
    * Adding one additional GND via to v1.1 PCB, add position file.
    * Migrate to IDF component manager
    [pcb-servo.kicad_pcb, pcb-servo.kicad_sch, pcb.kicad_pcb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]
2023-12-23 Correct build instructions and dependencies
    The code will only build with ESP-IDF v5.1.x (or newer). It has not been tested with ESP-IDF v5.2 or master at this time.
    Fixes https://github.com/atanisoft/Esp32OlcbIO/issues/11
